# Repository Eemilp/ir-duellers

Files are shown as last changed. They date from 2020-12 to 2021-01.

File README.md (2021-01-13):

# IR-duellers

Toy guns for a western-style duelling game. The pair of guns have an ir-LED and sensor each and can thus determine who shot first. When a gun "dies" it is not able to shoot anymore and has to be reset from a button to be functional again. 

A few images of the finished product: https://imgur.com/a/vaQRZun

## Electronics

The heart of the gun is an ATtiny85 with a TSOP312xx (TSOP31236 in this implementation) IR-receiver and an IR-LED. Additionally a status LED and a piezo-buzzer were added for feedback. 

A transistor was also added to amplify the IR-LEDs signal, but in hindsight this was unneccessary. The pizeo-buzzer could however have really done with some amplification, because it can be a bit too quiet sometimes. 

While operational everything runs on two AA batteries, but the design is 5v tolerant for programming purposes.  

The pcb also provides some breakout points for easier programming (VCC, GND, Reset, RX, TX). Unfotunately the internal clockspeed on the ATtiny85 seems to vary so much from chip to chip that it makes programming the chip over serial a hit or miss. Some chips seemed to work perfectly, while others just would not work. Therefore the chips were programmed with SPI. 

## Case

The case was designed in FreeCAD and 3d printed using PLA-plastic. Most parts are attached with screws but the trigger button is just slid in and held in place with friction. Note that the attachment of the top cover is not perfect and I have therefore used tape for fastening it as it's easier. 

The reset switch is a generic closing switch with a 7mm shaft. The trigger is a PS507MA, which is also a closing switch with a 16mm shaft.

------

## Software

Originally the program was written in the Arduino language. While this worked, an improved version was written in assembler. I have also included the version written in the Arduino language here, but be aware that it tends to be somewhat unreliable. Both versions here are programmed to work with 36kHz IR signal. 

Note that this project requires the ATTinyCore by SpenceKonde to be installed from the Arduino boards manager.

## Flashing the chips

The original plan was to program the chip over serial with the Arduino bootloader. This however did not appear to be reliable so programming the chips over SPI on a breadboard was used instead. An Arduino Uno (Arduino as ISP) was used as the programmer.

For the version written in assembler the hex file was generated with Atmel Studio and progamming was done with Avrdude. Avrdude comes with Arduino IDE and can be accessed over command line.

```bash

avrdude -CC:"\Path\to\Arduino\hardware\tools\avr/etc/avrdude.conf" -v -pattiny85 -carduino -PCOM3 -b19200 -U lfuse:w:0xE2:m -U hfuse:w:0xDF:m -U efuse:w:0xFF:m -Uflash:w:lightguns_asm_v1.hex:i

```

I have here the Arduino running Arduino as ISP on COM3. Also note the fuse settings. These set the internal oscillator at 8MHz and make sure that the chip can be programmed again using SPI.

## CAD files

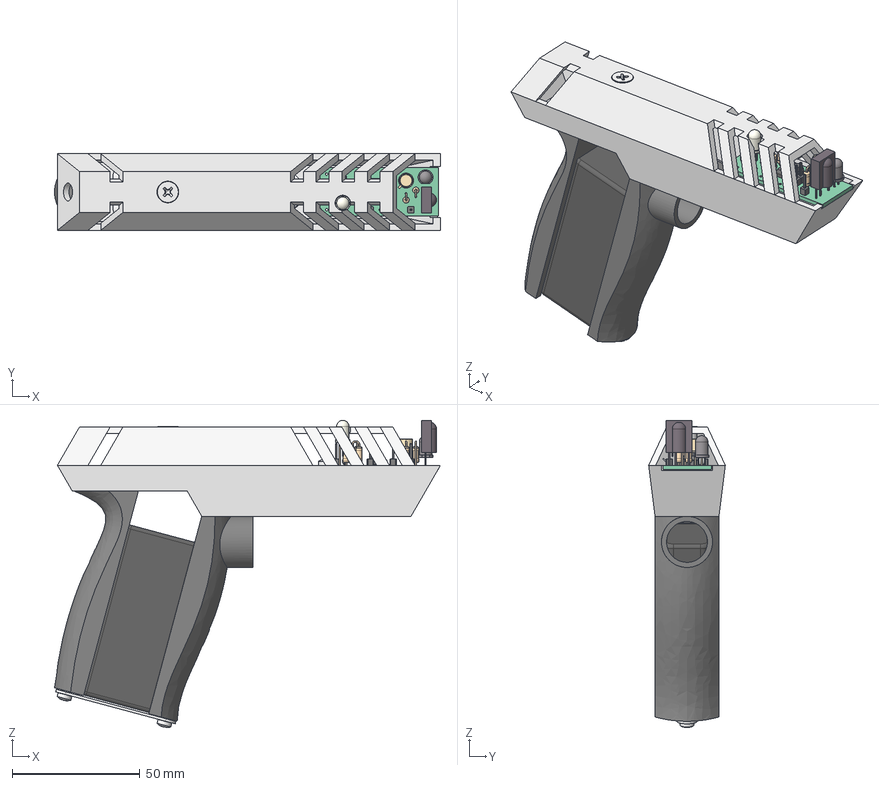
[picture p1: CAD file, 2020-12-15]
Hardware/case/Ir duellers.FCStd
151.1 x 30.0 x 120.3 mm
Pcb
R4_R_Axial_DIN0207_L63mm_D25mm_P254mm_Vertical_5CEDECB2
U1_DIP-8_W7.62mm_5CEDED09
R5_R_Axial_DIN0207_L63mm_D25mm_P254mm_Vertical_5CEDECC1
C1_C_Disc_D30mm_W16mm_P250mm_5CEDEBA8
D1_LED_D5.0mm_Clear_5CEDEBBA
D2_LED_D5.0mm_IRGrey_5CEDEBCC
J2_PinHeader_1x01_P254mm_Vertical_5CEDEBF7
J3_PinHeader_1x01_P254mm_Vertical_5CEDEC0C
J4_PinHeader_1x01_P254mm_Vertical_5CEDEC21
J5_PinHeader_1x01_P254mm_Vertical_5CEDEC36
J6_PinHeader_1x01_P254mm_Vertical_5CEDEC4B
Q1_TO-18-3_5CEDEC76
R1_R_Axial_DIN0207_L63mm_D25mm_P254mm_Vertical_5CEDEC85
R2_R_Axial_DIN0207_L63mm_D25mm_P254mm_Vertical_5CEDEC94
R3_R_Axial_DIN0207_L63mm_D25mm_P254mm_Vertical_5CEDECA3
U2_Vishay_CAST-3pin_5CEDED2A
C2_C_Disc_D30mm_W16mm_P250mm_5CF017E2
battery case
bottom base
front grip
back grip
top base
piezo
M4x8-Screw back grip
M4x8-Screw back grip001
M3x8-Screw
M4x8-Screw top
M3x8-Screw front grip
M3x8-Screw front grip001
M3x8-Screw bottom
M3x8-Screw bottom001
top support
bottom

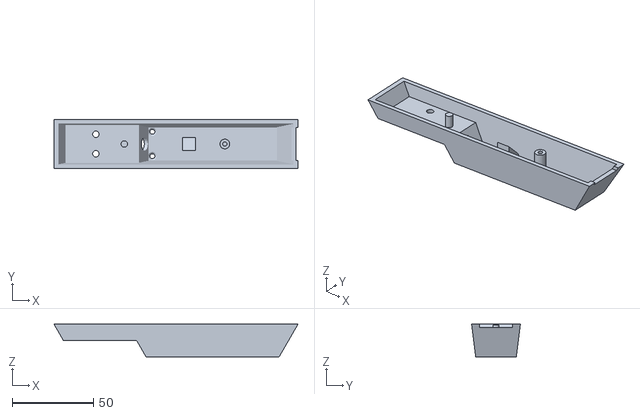
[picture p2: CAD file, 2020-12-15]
Hardware/case/stl/bottom base.stl
150.0 x 30.0 x 20.0

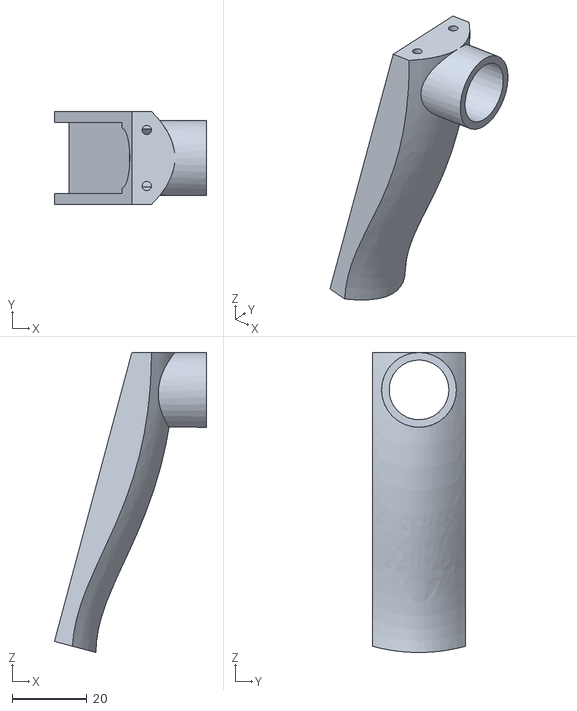
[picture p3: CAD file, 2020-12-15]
Hardware/case/stl/front grip.stl
40.7 x 25.0 x 80.2

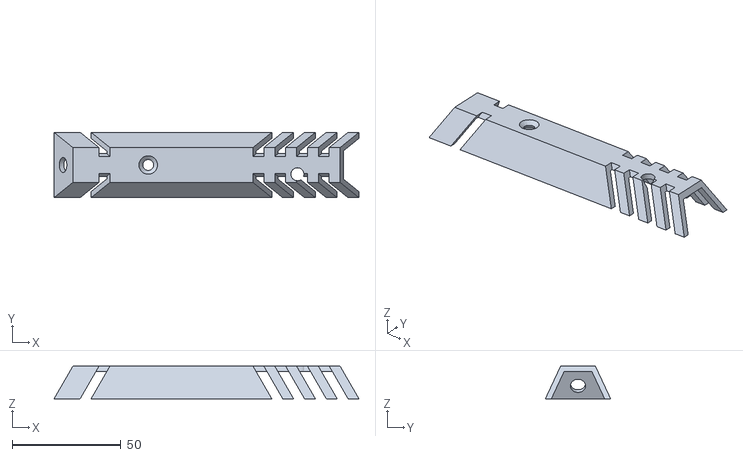
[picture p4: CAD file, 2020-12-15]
Hardware/case/stl/top base.stl
140.0 x 30.0 x 15.0

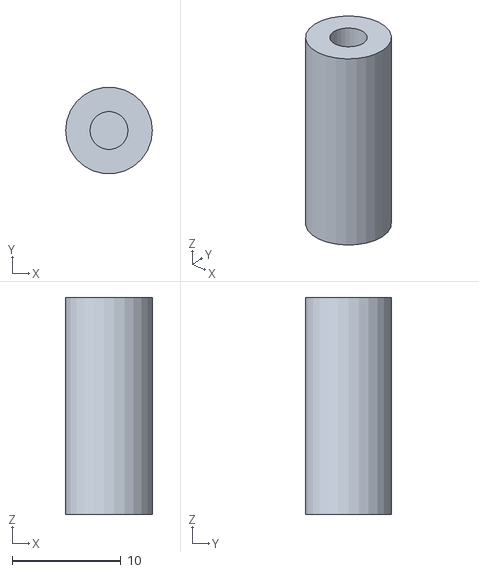
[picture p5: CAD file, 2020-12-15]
Hardware/case/stl/top support.stl
8.00 x 7.94 x 20.0

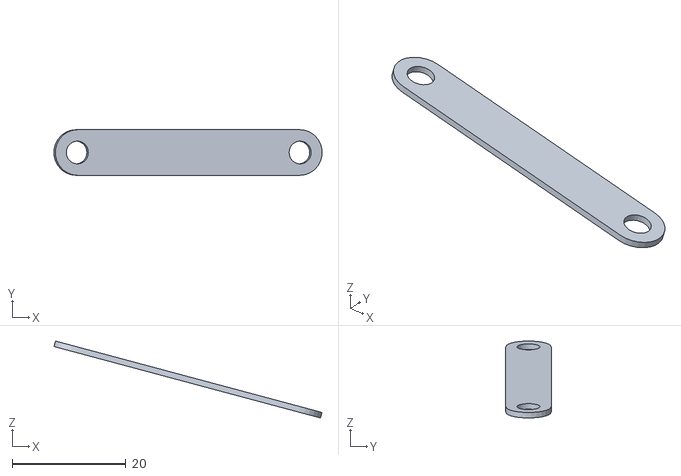
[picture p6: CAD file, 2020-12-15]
Hardware/case/stl/bottom support.stl
47.0 x 8.00 x 13.5

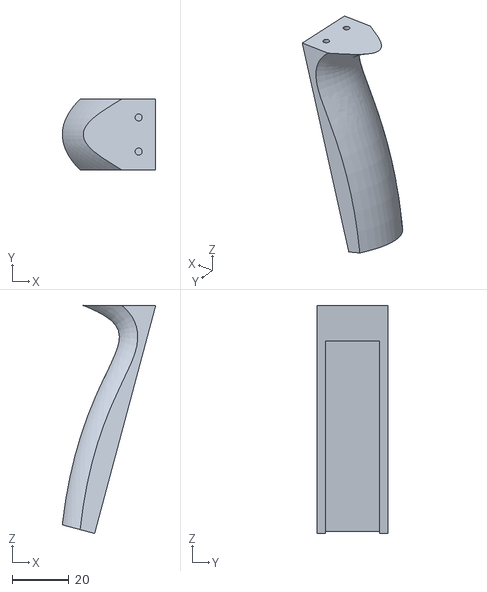
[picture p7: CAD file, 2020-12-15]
Hardware/case/stl/back grip.stl
32.9 x 25.0 x 80.2

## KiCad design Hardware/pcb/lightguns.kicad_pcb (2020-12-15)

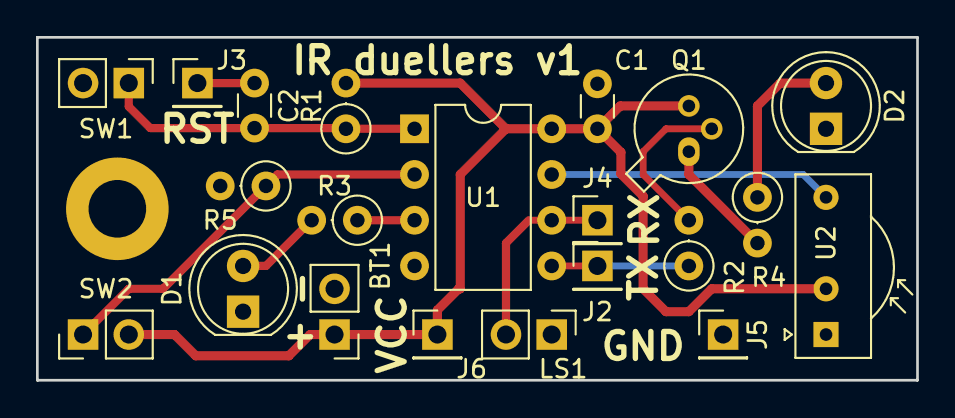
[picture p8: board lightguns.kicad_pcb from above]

Board: 2 copper layers, 48.9 x 19.1 mm, 21 parts (0 on the bottom side), 13 nets.

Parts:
BT1: Battery; PinHeader_1x02_P2.54mm_Vertical
C1, C2: 0.1uF; C_Disc_D3.0mm_W1.6mm_P2.50mm
D1: LED; LED_D5.0mm_Clear
D2: IR_LED; LED_D5.0mm_IRGrey
J2: TX; PinHeader_1x01_P2.54mm_Vertical
J3: RST; PinHeader_1x01_P2.54mm_Vertical
J4: RX; PinHeader_1x01_P2.54mm_Vertical
J5: GND; PinHeader_1x01_P2.54mm_Vertical
J6: VCC; PinHeader_1x01_P2.54mm_Vertical
LS1: SPKR; PinHeader_1x02_P2.54mm_Vertical
Q1: BC109; TO-18-3
R1, R5: 10k; R_Axial_DIN0207_L6.3mm_D2.5mm_P2.54mm_Vertical
R2: 1k; R_Axial_DIN0207_L6.3mm_D2.5mm_P2.54mm_Vertical
R3: 470; R_Axial_DIN0207_L6.3mm_D2.5mm_P2.54mm_Vertical
R4: 75; R_Axial_DIN0207_L6.3mm_D2.5mm_P2.54mm_Vertical
SW1: RST SW; PinHeader_1x02_P2.54mm_Vertical
SW2: TRIG; PinHeader_1x02_P2.54mm_Vertical
U1: ATtiny85-20PU; DIP-8_W7.62mm
U2: TSOP17xx; Vishay_CAST-3Pin

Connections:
+3V3: BT1.1, C1.1, J6.1, Q1.3, R1.2, SW2.2, U1.8, U2.2
GND: BT1.2, C1.2, D1.1, D2.1, J5.1, LS1.1, R5.2, SW1.2, U1.4, U2.1
unnamed: C2.1, J3.1
unnamed: C2.2, R1.1, SW1.1, U1.1
unnamed: D1.2, R3.2
unnamed: D2.2, R4.1
unnamed: J2.1, R2.1, U1.5
unnamed: J4.1, LS1.2, U1.6
unnamed: Q1.1, R4.2
unnamed: Q1.2, R2.2
unnamed: R3.1, U1.3
unnamed: R5.1, SW2.1, U1.2
unnamed: U1.7, U2.3

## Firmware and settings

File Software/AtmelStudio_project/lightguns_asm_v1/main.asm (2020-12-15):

;
; lightguns_asm_v1.asm
;
; Created: 13/04/2020 14:04:21
; Author : Eemil Praks
;
.org 0x0000
		rjmp start				;0x0000
		rjmp INT0_ISR			;0x0001


start:
		cli						;disabling interrupts to init everything
		ldi r19,(1 << CLKPCE)	;making sure that correct clockspeed is used
		clr r20
		out CLKPR, r19			;enabling clock prescaler change
		out CLKPR, r20			;changing clock prescaler to none.

		out WDTCR, r20			;disabling the watchdog timer
		ldi r19,(1 << ACD)		;powering down the analog comparator
		out ACSR, r19
		ldi r20,(1 << ISC01)		;setting interrupt 0 to fire at falling edge
		out MCUCR, r20
		ldi r19,(1 << DDB4)|(1 << DDB1)|(1 << DDB0) ;setting pins PB0, 1, 4 as outputs
		out DDRB, r19			;setting the pin settings

		ser r19					;setting timer 1 OC B and C registers to never trigger
		out OCR1C, r19			;these are used for delay function
		out OCR1B, r19

		ldi r25, 50				;setting delay for tones

		ldi r16,255				;ir pin not used on tone
		ldi r18,(1 << CS01)|(1 << CS00);setting prescaler to 64
		ldi r17, 208			;first 300Hz
		ldi r24, 0x0			;pulse counter

	wakeupToneLoop:				;playing wakeup sound
		rcall tone
		rcall delay
		rcall noTone
		subi r17, 25
		inc r24
		cpi r24, 7
		brne wakeupToneLoop

		ldi r19,(1 << INT0)		;enabling interrupt0
		out GIMSK, r19

		ldi r21, (1 << PB4)		;setting led on pin 4 on
		out PORTB, r21
		
		ldi r19,(1 << INTF0)	;clearing the int0 flag before interrupts are turned on
		out GIFR, r19
		sei						;enabling interrupts

		rjmp loop
tone:							;r16: OC0A r17: OC0B r18: Prescaler
		ldi r19,(1 << TSM)|(1 << PSR0);setting timer to synchro mode
		out GTCCR, r19
		ldi r19,(1 << OCF0A)|(1 << OCF0B)|(1 << TOV0);clearing interrupt flags
		out TIFR, r19
		

		out OCR0A,r16			;setting a (ir) compare register to register 16
		out OCR0B,r17			;setting b (piezo) compare match to register 17

		ldi r19,(1 << COM0A0)	;loading bit to r19 for setting 
		cp r16,r17				;checking which register is lower and setting pin ouput
		brlo ifneg				;skipping rightshifts if 16 is lower
		lsr r19
		lsr r19
		out OCR0A, r17
	ifneg:
		ori r19,(1 << WGM01)	;compare match mode on r19
		out TCCR0A, r19			;compare match register
		ldi r19, 0x0
		out TCNT0, r19			;setting counter to 0

		out TCCR0B,r18			;setting prescaler
		out GTCCR, r19			;setting timer out of synchro mode
		ret
noTone:
		clr r19
		out TCCR0B,r19			;stopping timer
		ret
delay:							;delay is stored in r25, a bit is 1.024ms
		out OCR1A,r25			;loading delay to interrupt
		ldi r19,(1 << CS13)|(1 << CS12)|(1 << CS11);see below
		out TCCR1, r19			;setting the prescaler -> timer runs
		
	delayLoop:					;checking if compare match a flag set
		in r19, TIFR
		sbrs r19, OCF1A
		rjmp delayLoop

		clr r19					;stopping delay timer
		out TCCR1, r19
		out TCNT1, r19			;clearing timer

		ldi r19, (1 << OCF1A)|(1 << OCF1B)|(1 << TOV1)
		out TIFR, r19			;clearing all timer 1 interrupt flags

		ret
loop:
		;TODO trigger
		in r19, PINB
		sbrs r19, PINB3			;skipping next jump if trigger set
		rjmp loop
		
		cbi PORTB, PB4			;clearing led
		ldi r16, 111			;sending ir signal
		ldi r17, 255
		ldi r18,(1 << CS00)		;setting prescaler to 8
		ldi r25, 5				;signal for 5ms
		cli						;disabling interrupt for tone duration
		rcall tone
		rcall delay
		rcall noTone
		ldi r19,(1 << INTF0)	;clearing the int0 flag so it wont trigger after the shot
		out GIFR, r19
		sei

		ldi r25, 10				;setting delay for tones

		ser r16					;ir pin not used on tone
		ldi r18,(1 << CS01)|(1 << CS00);setting prescaler to 64
		ldi r17, 15				;first 300Hz
		ser r24					;pulse counter
		ldi r23, 8				;time added

	trigToneLoop:				;playing gun sound
		rcall tone
		rcall delay
		add r17, r23
		inc r24
		cpi r24, 14
		brne trigToneLoop
		rcall noTone

		ldi r25, 250			;delay after shot
		rcall delay
		sbi PORTB, PB4			;clearing led

		rjmp loop				;returning to alive loop
INT0_ISR:
		;cli					;cli run by hardware during interrupt
death:							;recovering peripherals and going to loop
		clr r19					;stopping timers if running to prevent unexpected behaviour
		out TCCR0B, r19
		out TCCR1, r19
		out GIMSK, r19			;stopping int0

		ser r19
		out TIFR, r19			;clearing all timer interrupt flags for delay function

		ldi r19,LOW(RAMEND)		;resetting stack pointer
		out SPL,r19
		ldi r19,HIGH(RAMEND)
		out SPH,r19

		cbi PORTB, PB4			;turning off led

		ldi r25, 45				;setting delay for tones

		ldi r16,255				;ir pin not used on tone
		ldi r18,(1 << CS01)|(1 << CS00);setting prescaler to 64
		ldi r17, 20			;first 300Hz
		clr r24					;pulse counter
		clr	r23					;pulse counter 2
		ldi r22, 25				;tone diff

	deadToneLoop:				;playing decending tone
		rcall tone
		rcall delay
		rcall noTone
		add r17, r22
		inc r24
		cpi r24, 7
		brne deadToneLoop

		inc r23					;playing the decending tone for 3 times
		clr r24
		ldi r17, 20
		cpi r23, 3
		brne deadToneLoop

		ldi r25, 220			;setting delay for dead loop
		clr r19					;used as reference below
dead:	
		sbi PORTB, PB4			;heartbeat blink
		rcall delay
		cbi	PORTB, PB4
		rcall delay
		sbi PORTB, PB4
		rcall delay
		cbi	PORTB, PB4
		rcall delay
		ldi r24, 6
		rcall delay
		rcall delay
		rcall delay

		rjmp dead				;returning to loop

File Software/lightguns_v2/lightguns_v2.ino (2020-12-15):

volatile bool alive = true;//boolean to determine guns state

const uint8_t IRfrequency = 36000;
const unsigned long signalLenght = 50; //milliseconds

unsigned long lastShot;

unsigned long hitBegan;

const unsigned long hitLenght = 20;

const unsigned long delayBetweenShots = 150;

//pin numbering
const int trigPin = 3;
const int sensorPin = 2;
const int IRpin = 0;
const int piezoPin = 1;
const int statusLedPin = 4;

void setup() {

  pinMode(trigPin, INPUT);
  pinMode(sensorPin, INPUT);
  pinMode(IRpin, OUTPUT);
  pinMode(piezoPin, OUTPUT);
  pinMode(statusLedPin, OUTPUT);

  ADCSRA &= (~(1 << ADEN)); //turning ADC off, because it's not used

  for (int i = 1000; i > 300; i = i - 100) {
      tone(piezoPin, i, 50); //generating the gun sound
      delay(50);
  }
  
  digitalWrite(statusLedPin, HIGH);//letting know that the gun is ready

  while (alive == true) {
    
    if (digitalRead(trigPin) == HIGH && millis() - lastShot > delayBetweenShots) {//sending IR signal, lastShot for moderating fire rate
      
      for(unsigned long i = 0; i <= 36000; i++){ //sending the IR signal, this might need calibration!
        digitalWrite(IRpin, HIGH);
        delayMicroseconds(5);
        digitalWrite(IRpin, LOW);
        delayMicroseconds(4);
      }

      for (int i = 10000; i > 300; i = i - 150) {
        tone(piezoPin, i, 2); //generating the gun sound
        delay(2);
      }
      lastShot = millis();
    }

    //checking if ir signal has been recieved. Sensor returns LOW on signal.
    //In some conditions when the signal is not received well this can cause problems!
    if (digitalRead(sensorPin) == LOW) {
      
      hitBegan = millis();
      
      while(digitalRead(sensorPin) == LOW){
        //empty loop while recieving signal
      }

      if(millis() - hitBegan > hitLenght){//checking if recieved signal was long enough
      alive = false;
      }
    }
  }

  digitalWrite(IRpin, LOW);
  digitalWrite(statusLedPin, LOW); //letting know that player lost.
  //death sound effect
  for (int k = 0; k < 30; k++) {
    int toneLenght = 0;
    toneLenght = random(5, 50);
    tone(piezoPin, random(100, 1500), toneLenght);
    delay(toneLenght);
  }
  delay(200);
  for (int k = 0; k < 3; k++) {
    for (int i = 1000; i > 300; i = i - 100) {
      tone(piezoPin, i, 50); //generating the gun sound
      delay(50);
    }
  }

}

void loop() {
  //do nothing when we are dead
}
